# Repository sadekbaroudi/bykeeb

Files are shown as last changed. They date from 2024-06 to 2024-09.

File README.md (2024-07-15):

# bykeeb (baby yoda keyboard)

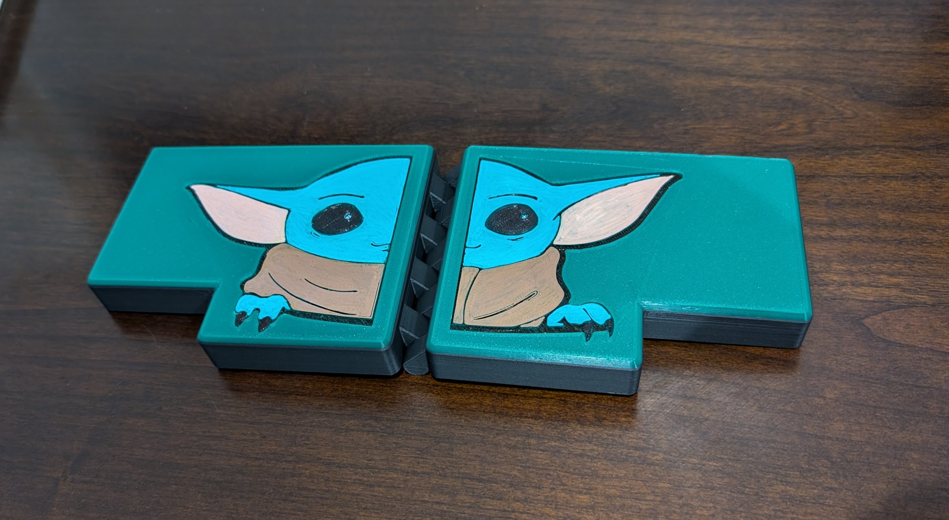
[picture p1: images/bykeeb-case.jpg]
bykeeb-case

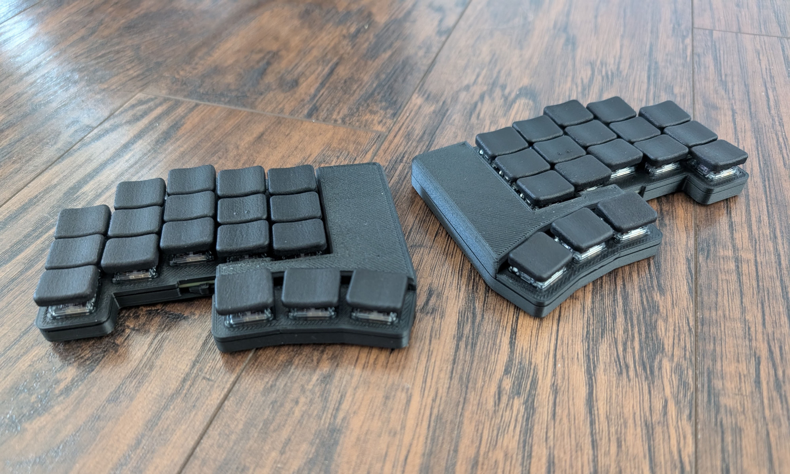
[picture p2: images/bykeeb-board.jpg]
bykeeb-board

bykeeb-in-case

## overview
bykeeb stands for "Baby Yoda Keyboard"

This is a 36 key wireless keyboard using a seeed xiao nrf52840 controller, supporting choc, gateron low profile, and MX switches.

### key features
* 36 keys
* seeed xiao nrf52840 controller
* hotswap or direct solder support for choc, gateron low profile, and MX switches
* battery cutout in pcb for a 32mm x 20mm x 6mm battery
* battery through holes for soldering a JST connector or direct wire
* on/off switch
* reset switch

### important notes
* This keyboard is wireless only. You cannot use a xiao rp2040.
* The switch spacing on this board is what I call min-y standard-x spacing. This is 19mm x 16mm. In the pictures above, I'm using [CMY keycaps](https://github.com/sadekbaroudi/fingerpunch/tree/master/keycaps/CMY).

## firmware

Firmware is done in [ZMK](https://zmk.dev/), and can be found in the [zmk-fingerpunch-keyboards](https://github.com/sadekbaroudi/zmk-fingerpunch-keyboards) github repository, specifically in the `boards/shields/bykeeb` directory.

## build guide

see the [build guide](buildguide/README.md) for more info

## case

see the [case readme](cases/README.md) for more info

## fabrication

Use the `gerber.zip` found in the [pcb directory](pcb/mx-choc-ks-27/production). If you are using [jlcpcb](jlcpcb.com), you can also use the `bom.csv` and `positions.csv` to do PCBA

## LICENSE

Free to use for personal use only. Any derivitive work must reference the author by name, link to [https://github.com/sadekbaroudi/bykeeb](https://github.com/sadekbaroudi/bykeeb), and propagate this license text. No commercial use of this work or any of its derivatives.

THE CONTENT OF THIS REPOSITORY IS PROVIDED "AS IS", WITHOUT WARRANTY OF ANY KIND, EXPRESS OR IMPLIED, INCLUDING BUT NOT LIMITED TO THE WARRANTIES OF MERCHANTABILITY, FITNESS FOR A PARTICULAR PURPOSE AND NONINFRINGEMENT. IN NO EVENT SHALL THE AUTHORS OR COPYRIGHT HOLDERS BE LIABLE FOR ANY CLAIM, DAMAGES OR OTHER LIABILITY, WHETHER IN AN ACTION OF CONTRACT, TORT OR OTHERWISE, ARISING FROM, OUT OF OR IN CONNECTION WITH THE SOFTWARE/HARDWARE OR THE USE OR OTHER DEALINGS IN THE SOFTWARE/HARDWARE.

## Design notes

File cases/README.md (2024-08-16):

# bykeeb case

## parts

For this build, you'll need:
| Required or Optional | Quantity | Part | Notes | 
| --- | --- | --- | --- |
| Required | 1 | left body | |
| Required | 1 | right body | |
| Optional | 1 | left cover | |
| Optional | 1 | right cover | |
| See notes | 1 | left switch plates | Only optional for for choc / glp, required for MX |
| See notes | 1 | right switch plates | Only optional for for choc / glp, required for MX |
| See notes | 6 | M2 heat set inserts, 3.5mm diameter, 3.5-4mm length | Only required if you are using the left and right covers |
| See notes | 6 | M2 screws, 5mm | Only required if you are using the left and right covers |
| Optional | 1 | left on/off switch cover | |
| Optional | 1 | right on/off switch cover | |

### explanation of file names

* `bykeeb-on-off-switch-long` vs `bykeeb-on-off-switch-short` - the long will not fit in the carrying case, but is more convenient to switch on and off. The short one will fit in the carrying case
* `bykeeb-body-left-inset-0.2mm` - The `inset-0.2mm` models go in 0.2mm in the inside perimeter of the body. It's a bit of a tighter fit for the pcb. This is in case the pcb doesn't snap fit into the body well enough for the non-inset version.

## renders
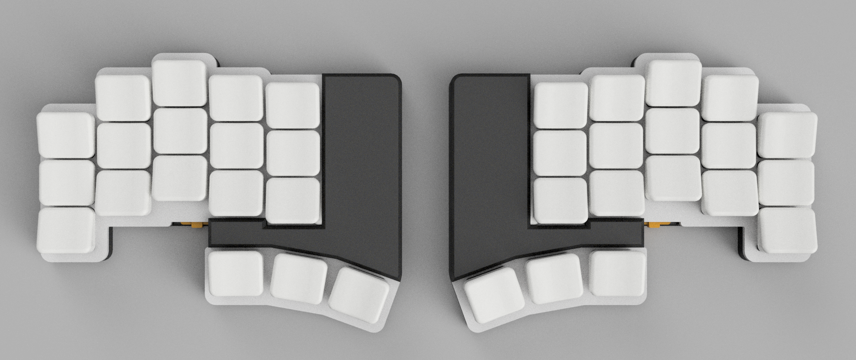
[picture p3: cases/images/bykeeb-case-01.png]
bykeeb-case-01

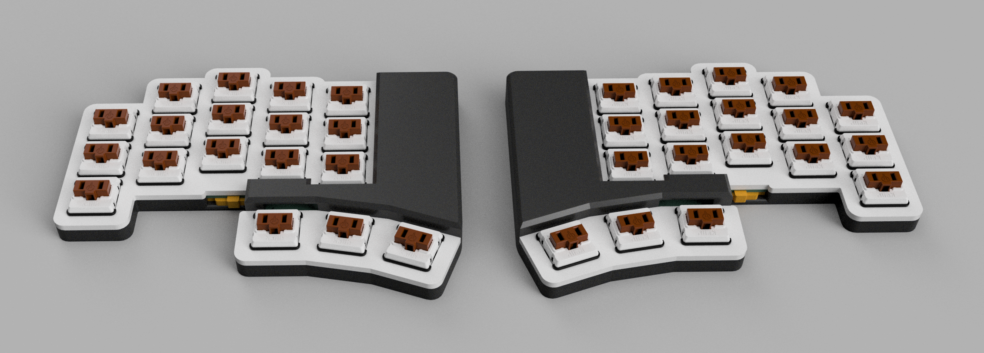
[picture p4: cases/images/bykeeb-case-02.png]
bykeeb-case-01

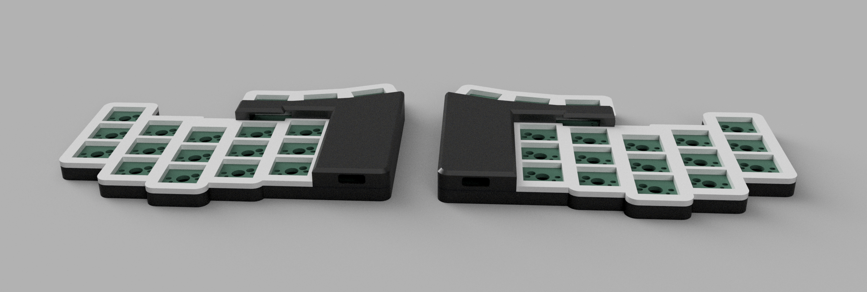
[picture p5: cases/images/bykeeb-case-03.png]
bykeeb-case-01

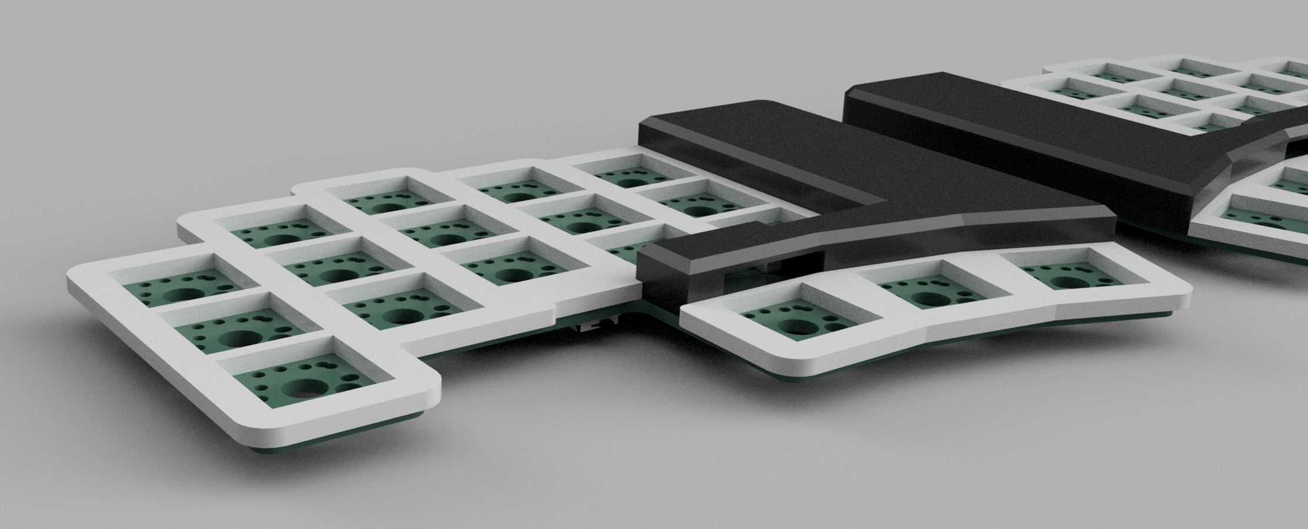
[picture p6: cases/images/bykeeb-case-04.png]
bykeeb-case-01

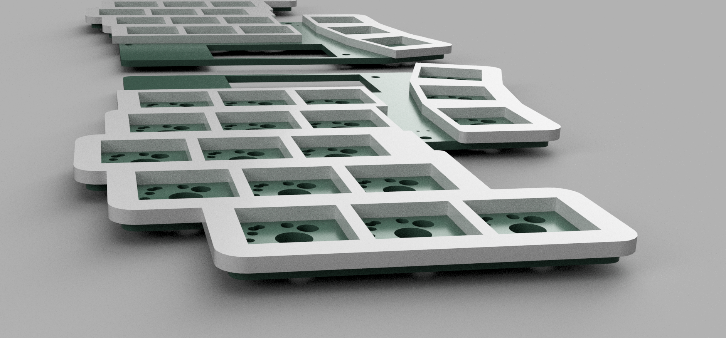
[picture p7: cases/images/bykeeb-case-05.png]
bykeeb-case-01

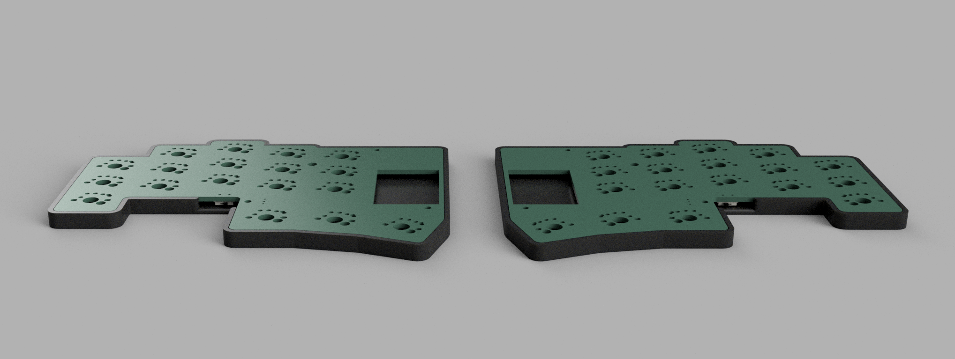
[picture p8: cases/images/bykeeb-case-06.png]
bykeeb-case-01

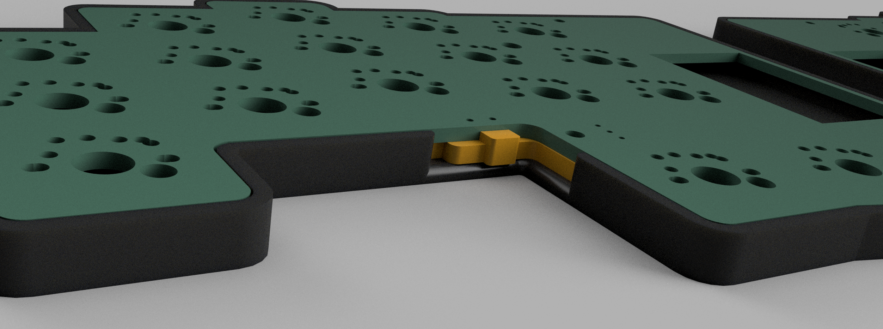
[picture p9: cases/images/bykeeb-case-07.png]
bykeeb-case-01


## assembly

The pcb is a press fit into the body.

For the cover, you should melt the heat set inserts into the mounting points, and then screw into the heat set inserts from the bottom of the pcb.

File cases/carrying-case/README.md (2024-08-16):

# bykeeb carrying case

There are effectively two versions of this case. The print-in-place and the hinge-assembly-required versions. The difference between these two is that the print in place requires that you print the whole case in one print. Recognizing that some print beds are not large enough to accommodate this, I also included the hinge-assembly-required version. In this version, the center hinge for the case is hollowed out to allow you to independently print the left and right halves.

## Print in place

### parts

For this build, you'll need:
| Quantity | Part | Notes |
| --- | --- | --- |
| 6 | 8mm x 3mm magnets | |
| 1 | Rod with diameter: 4.5mm - 5mm and length: ~95mm | |

## Hinge assembly required

## parts

For this build, you'll need:
| Quantity | Part | Notes | 
| --- | --- | --- |
| 6 | 8mm x 3mm magnets | |
| 1 | Rod with diameter: 4.5mm - 5mm and length: ~95mm | The rod should have a mechanism to screw in or cap at either end to allow you to use it as a hinge for the two halves. I don't have any recommendations on where to get this, as I haven't built one myself. |
| 1 | (alternate to rod above) hinge-center-piece stl | If you can print this, it should fit in the center. Not sure how reliable it will be, but worth trying! |

## Magnet assembly

For the magnets on each of these cases, you should put a touch of super glue in the holes for the magnets, and press them in. Be very careful to make sure the magnet's polarity is correct between the two halves!

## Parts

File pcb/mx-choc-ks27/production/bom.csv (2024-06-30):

Designator | Footprint | Quantity | Value | LCSC Part #
 |  | 1
D1, D10, D11, D12, D13, D14, D15, D16, D17, D18, D19, D2, D20, D21, D22, D23, D24, D25, D26, D27, D28, D29, D3, D30, D31, D32, D33, D34, D35, D36, D4, D5, D6, D7, D8, D9 | D_SOD-123 | 36 | 1N4148W | C909967
H1, H2, H3, H4, H5, H6 | MountingHole_2.2mm_M2_DIN965_Pad | 6 | MountingHole
H10, H7, H8, H9 | Breakaway_Tabs | 4 | Breakaway Tabs
H11, H12 | MountingHole_3.2mm_M3 | 2 | MountingHole
J1, J2 | JST_PH_S3B-PH-K_1x03_P2.00mm_Horizontal | 2 | Conn_01x03_Female | C157929
M1, M2 | xiao-ble-smd-cutout | 2 | XIAO-BLE
SW1, SW10, SW11, SW12, SW13, SW14, SW15, SW16, SW17, SW18, SW19, SW2, SW20, SW21, SW22, SW23, SW24, SW25, SW26, SW27, SW28, SW29, SW3, SW30, SW31, SW32, SW33, SW34, SW35, SW36, SW4, SW5, SW6, SW7, SW8, SW9 | gateron-ks27-choc-v1-mx-soldered-and-hotswap | 36 | SW_Push
SW37, SW38 | MSK-12C02 | 2 | SW_DPDT | C431540
U1, U2 | SKQG-1155865 | 2 | SW_Push

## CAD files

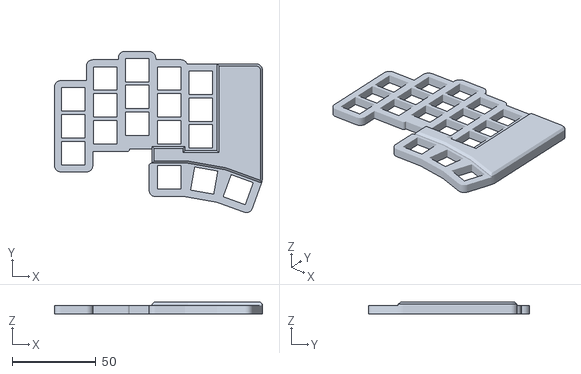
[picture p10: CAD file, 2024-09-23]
cases/bykeeb-cover-integrated-switchplate-mx-left.stl
124.0 x 96.1 x 7.00

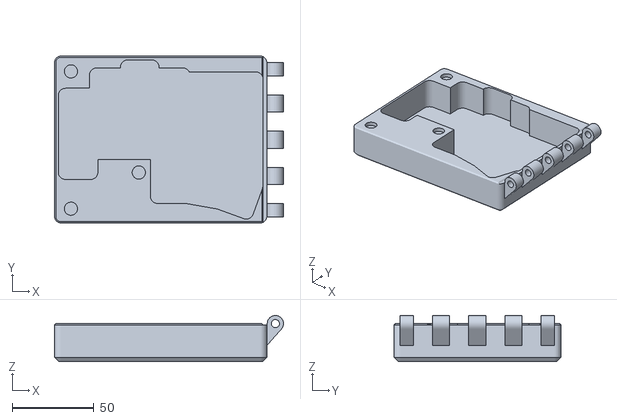
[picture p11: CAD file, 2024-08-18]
cases/carrying-case/hinge-assembly-required/bykeeb-carrying-case-16.7mm-inner-depth-left.stl
140.2 x 102.2 x 28.2

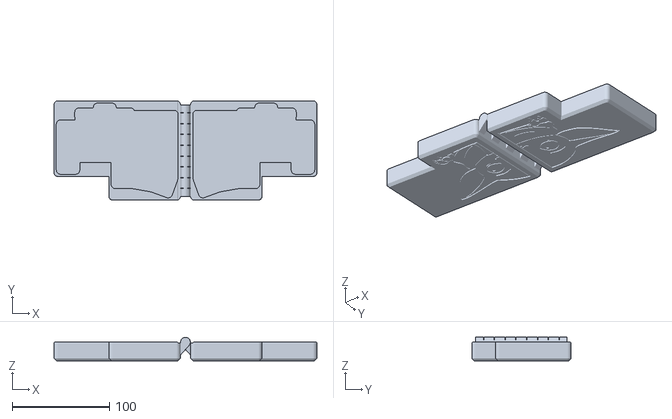
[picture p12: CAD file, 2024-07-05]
cases/carrying-case/print-in-place/bykeeb-carrying-case-16.7mm-inner-depth-non-boxed-grogu-emboss.stl
270.4 x 102.2 x 24.2

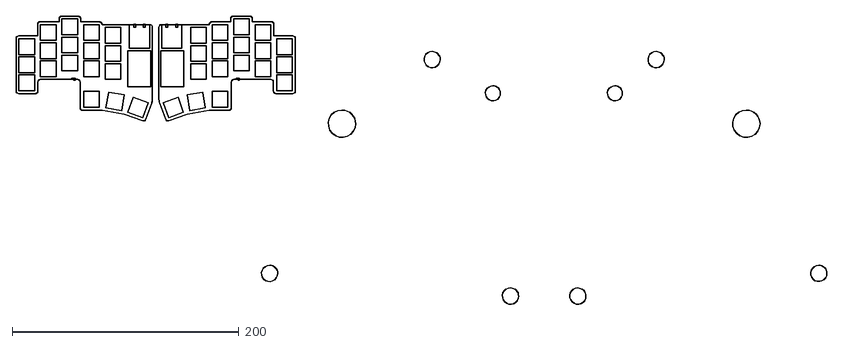
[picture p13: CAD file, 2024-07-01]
svgs/bykeeb-case-sketch.dxf
715.8 x 254.9

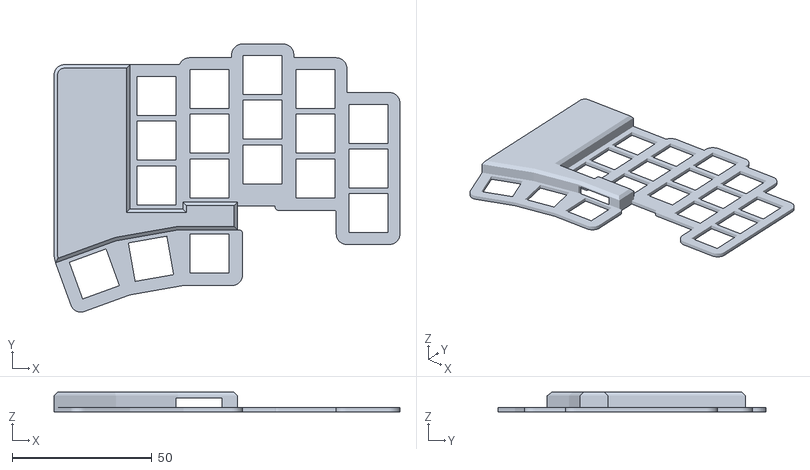
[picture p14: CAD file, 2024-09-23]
cases/bykeeb-cover-integrated-switchplate-choc-right.stl
124.0 x 96.1 x 7.00

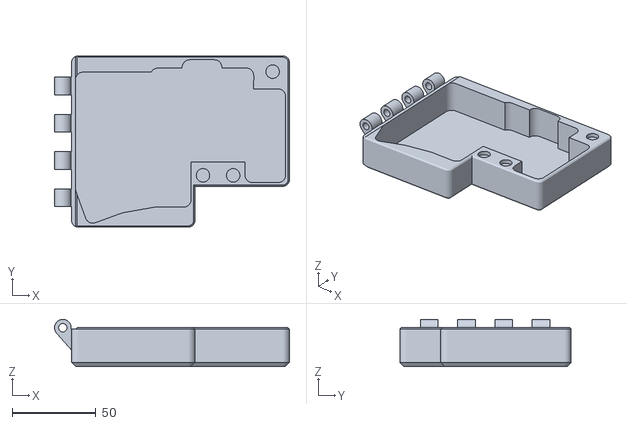
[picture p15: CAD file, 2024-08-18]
cases/carrying-case/hinge-assembly-required/bykeeb-carrying-case-non-boxed-20.7mm-inner-depth-right.stl
140.2 x 102.2 x 28.2

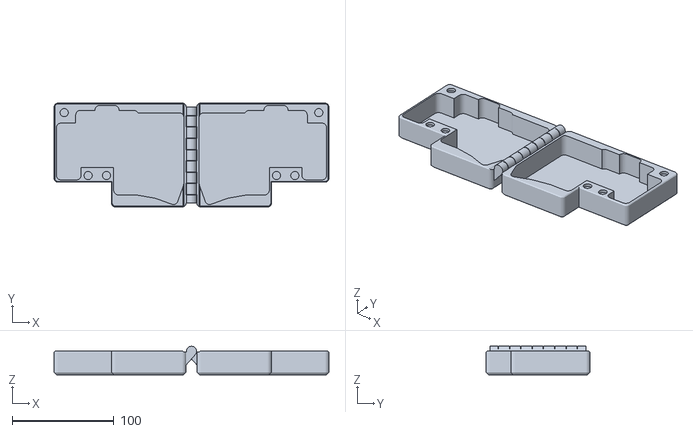
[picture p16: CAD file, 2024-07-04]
cases/carrying-case/print-in-place/bykeeb-carrying-case-20.7mm-inner-depth-non-boxed.stl
270.4 x 102.2 x 28.2

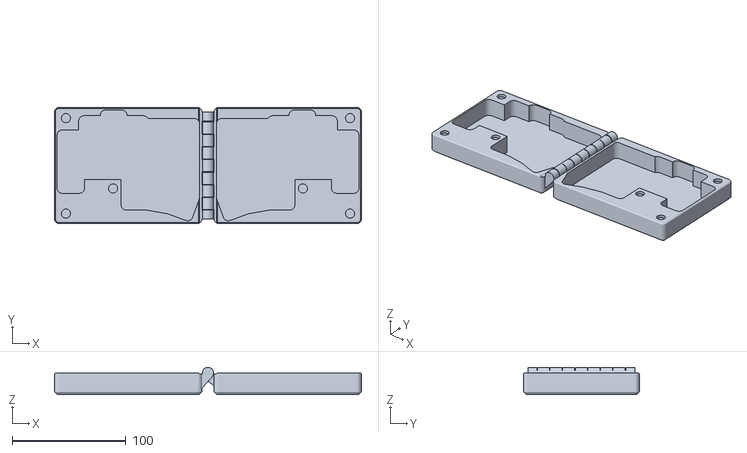
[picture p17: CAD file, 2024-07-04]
cases/carrying-case/print-in-place/bykeeb-carrying-case-16.7mm-inner-depth.stl
270.4 x 102.2 x 24.2

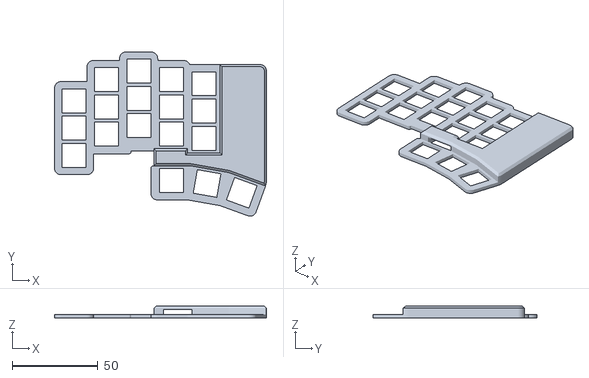
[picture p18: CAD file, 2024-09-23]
cases/bykeeb-cover-integrated-switchplate-glp-left.stl
124.0 x 96.1 x 7.00

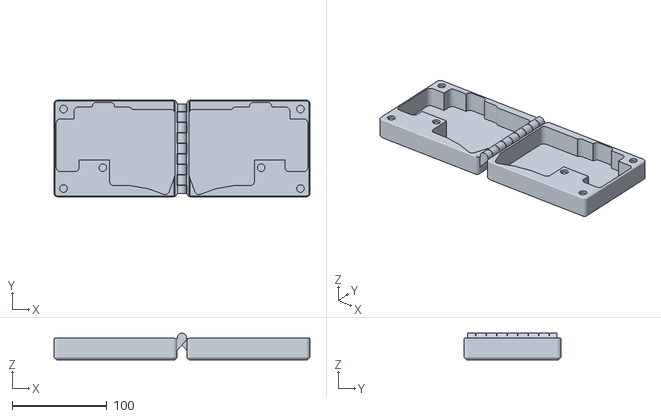
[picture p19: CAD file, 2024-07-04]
cases/carrying-case/print-in-place/bykeeb-carrying-case-20.7mm-inner-depth.stl
270.4 x 102.2 x 28.2

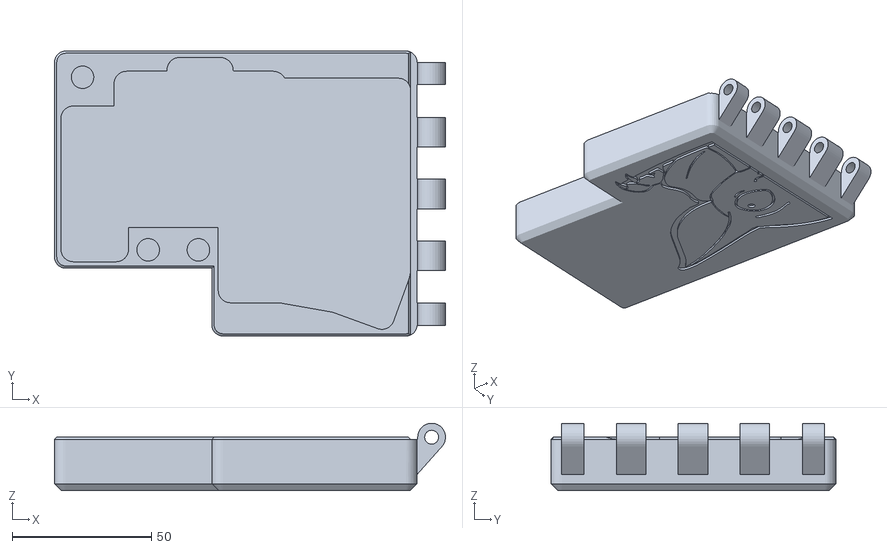
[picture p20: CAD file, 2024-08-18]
cases/carrying-case/hinge-assembly-required/bykeeb-carrying-case-non-boxed-16.7mm-inner-depth-grogu-emboss-left.stl
140.2 x 102.2 x 24.2

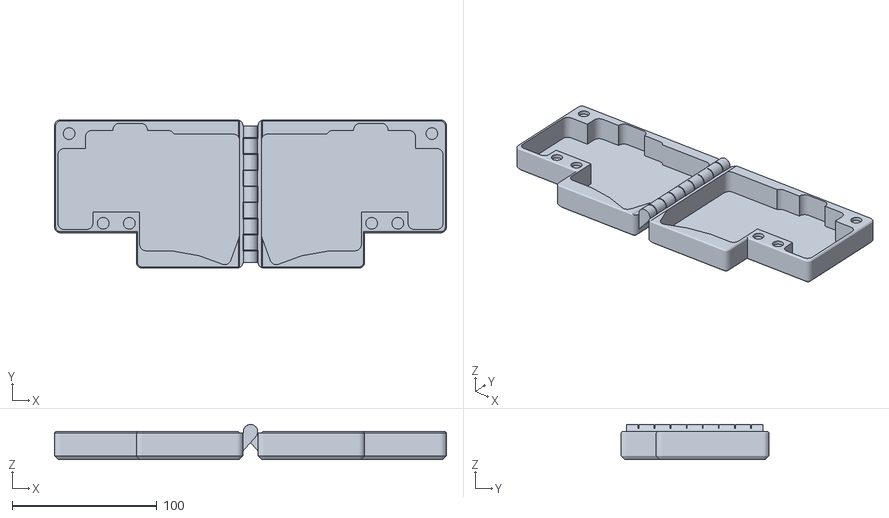
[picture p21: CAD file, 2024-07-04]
cases/carrying-case/print-in-place/bykeeb-carrying-case-16.7mm-inner-depth-non-boxed.stl
270.4 x 102.2 x 24.2

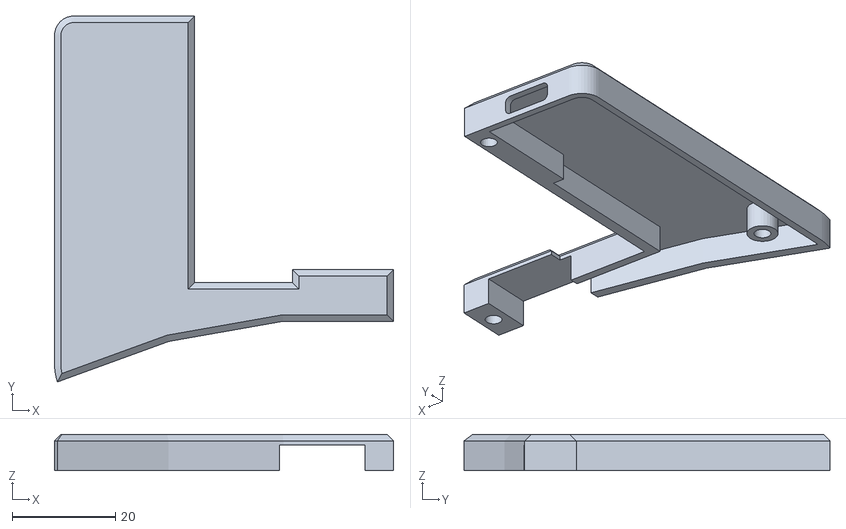
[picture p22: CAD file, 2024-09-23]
cases/bykeeb-cover-right.stl
65.8 x 71.0 x 7.00

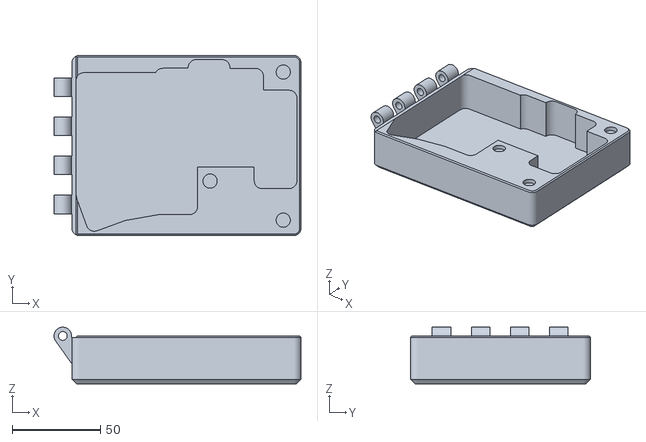
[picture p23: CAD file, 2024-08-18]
cases/carrying-case/hinge-assembly-required/bykeeb-carrying-case-20.7mm-inner-depth-right.stl
140.2 x 102.2 x 32.2

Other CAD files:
cases/bykeeb-cover-integrated-switchplate-mx-right.stl
cases/carrying-case/hinge-assembly-required/bykeeb-carrying-case-16.7mm-inner-depth-right.stl
cases/carrying-case/hinge-assembly-required/bykeeb-carrying-case-non-boxed-20.7mm-inner-depth-left.stl
cases/bykeeb-cover-integrated-switchplate-choc-left.stl
cases/bykeeb-body-left-inset-0.2mm.stl
cases/bykeeb-body-left.stl
cases/bykeeb-body-right-inset-0.2mm.stl
cases/bykeeb-body-right.stl
cases/bykeeb-cover-integrated-switchplate-glp-right.stl
cases/bykeeb-cover-left.stl
cases/bykeeb-on-off-switch-long-left.stl
cases/bykeeb-on-off-switch-long-right.stl
cases/bykeeb-on-off-switch-short-left.stl
cases/bykeeb-on-off-switch-short-right.stl
cases/bykeeb-switchplate-choc-or-glp-alphas.stl
cases/bykeeb-switchplate-choc-or-glp-thumbs.stl
cases/bykeeb-switchplate-mx-alphas.stl
cases/bykeeb-switchplate-mx-thumbs.stl
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

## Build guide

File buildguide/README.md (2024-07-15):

# build guide

## steps

(Note that there are additional images at the bottom of this guide as references for the build process)

1. Solder all the diodes. The line marking on the diode should be on the side closer to the diode silkscreen with a vertical line closing off the two horizontal lines
2. Solder the reset switch. The orientation doesn't matter
3. Solder the on/off switch. There is only one orientation for this. After soldering, **make sure the switch is in the off position**.
4. If using hotswap, solder all the hotswap sockets
5. Pre-solder the pads on the xiao controller, as shown below. For the battery pads, try to get only half the pad. If you get the right half covered in solder, the xiao pcb won't sit flush on the bykeeb pcb.
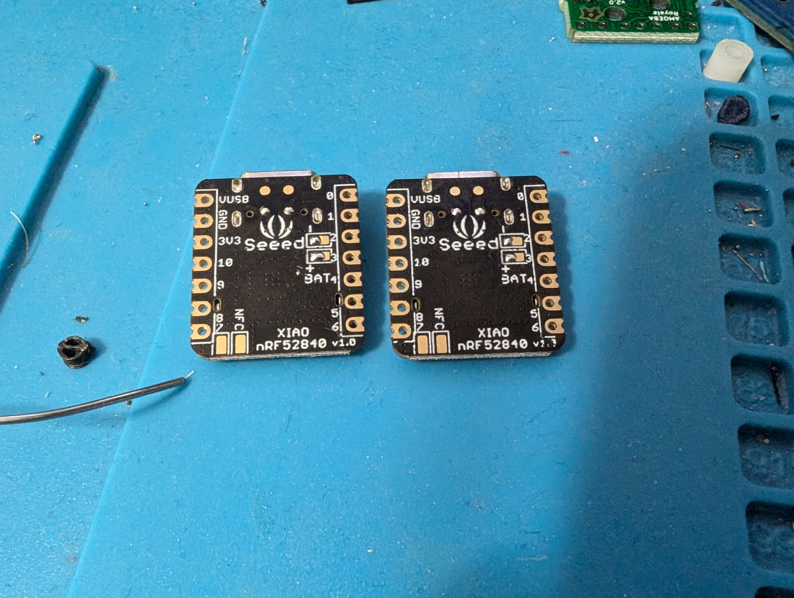
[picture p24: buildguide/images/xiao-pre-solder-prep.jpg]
bykeeb-image

6. After soldering all the castellated pads of the xiao to the top side of the bykeeb, flip the board over and solder the through holes. The reason that wetting the pads in step 5 was important is that now you can pull the solder up with the soldering iron to make a good connection. See below.
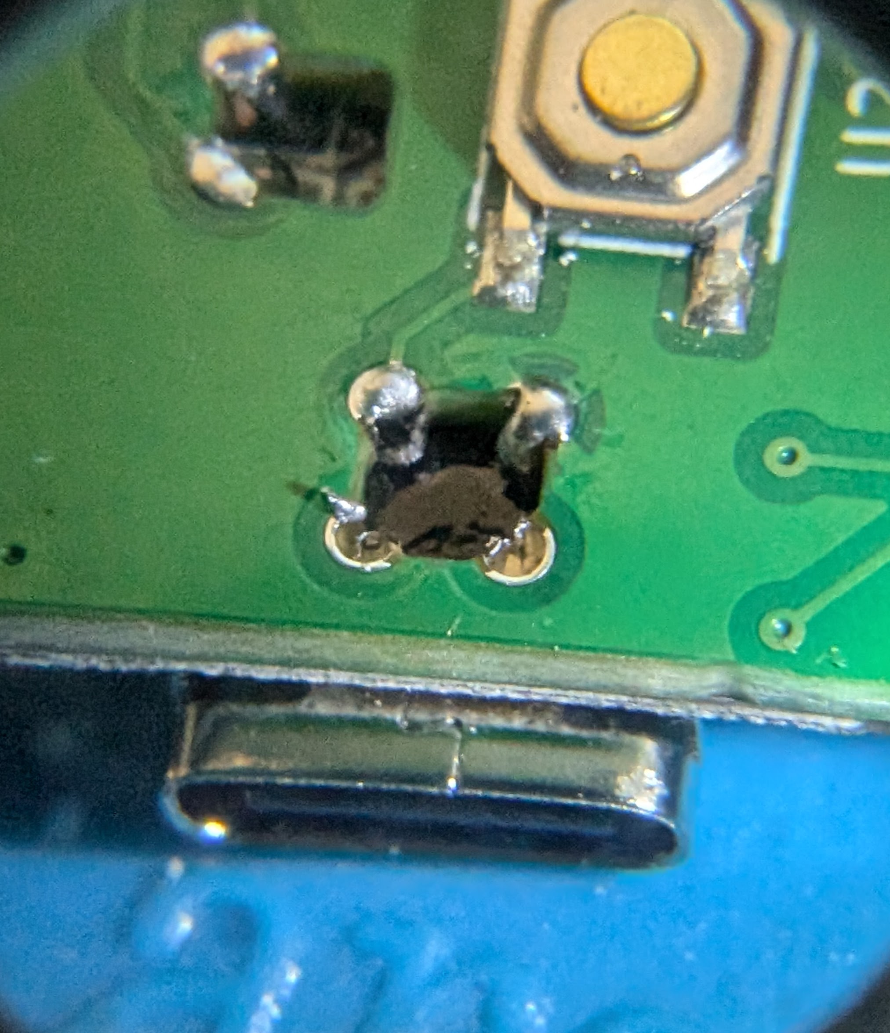
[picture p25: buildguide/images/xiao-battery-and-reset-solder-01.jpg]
bykeeb-image

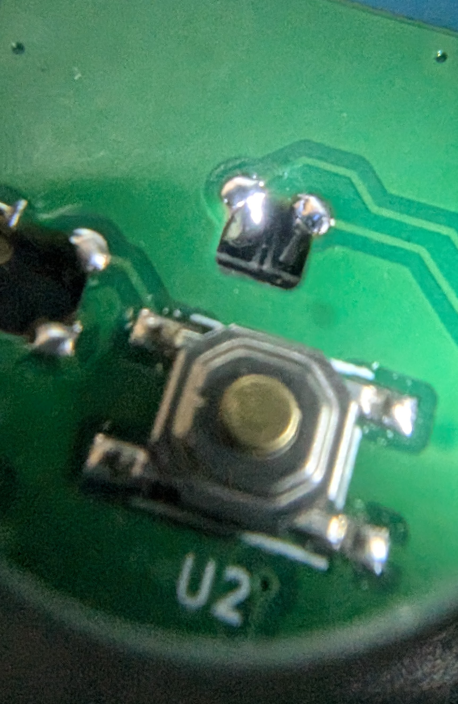
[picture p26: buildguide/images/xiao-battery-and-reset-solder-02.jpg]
bykeeb-image

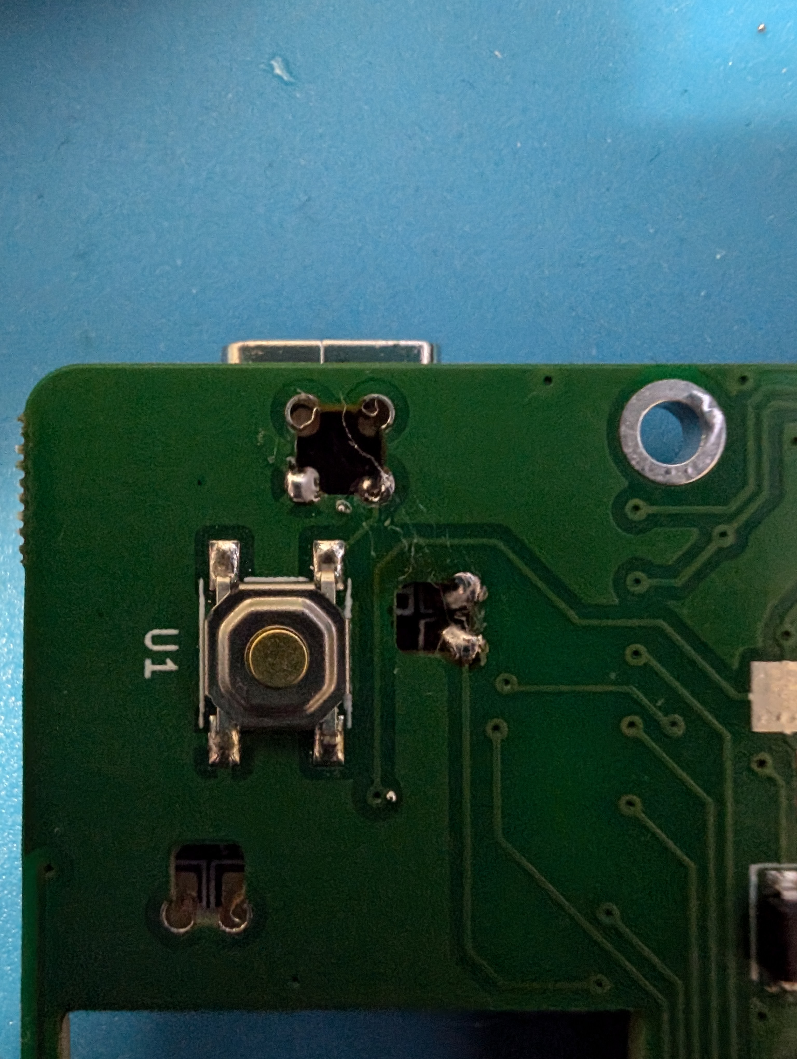
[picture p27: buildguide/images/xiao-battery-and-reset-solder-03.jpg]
bykeeb-image

7. If you're building without hotswap sockets, place the switches into the through holes, and solder them. Please note that if you want to use switch plates, you **must** have them in place before this step, or you won't be able to add them later.
8. Solder the JST connector to the top sides of the bykeeb halves. It is very important that you know the polarity of your battery before soldering this. You can plug in the battery into the JST connector before soldering. The through holes on the outside are the B- (ground) connections, and the single center through hole is the B+ (VCC). So, the red wire of the battery should go to the center through hole (B+).

You're done assembling the PCB!

## images

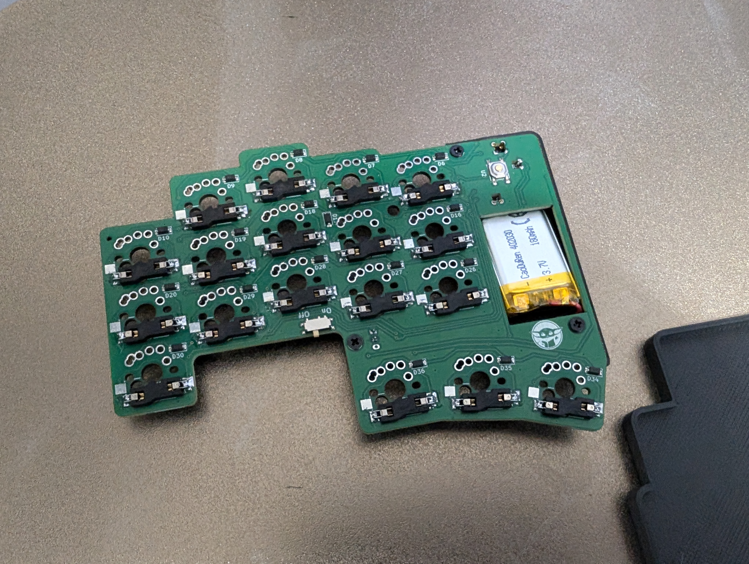
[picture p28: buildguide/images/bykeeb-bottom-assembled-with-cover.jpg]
bykeeb-image

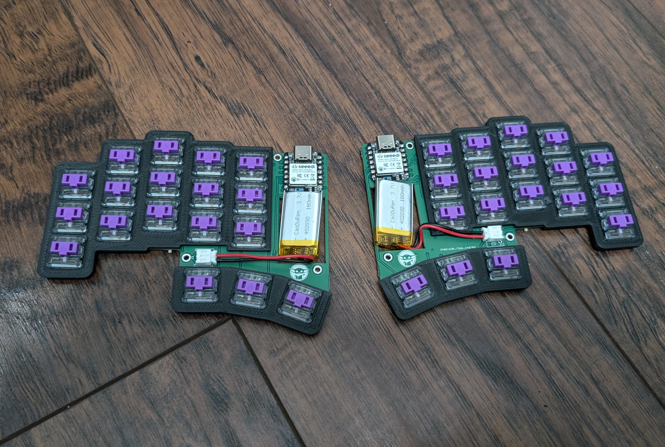
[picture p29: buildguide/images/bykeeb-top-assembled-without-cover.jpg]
bykeeb-image

bykeeb-image
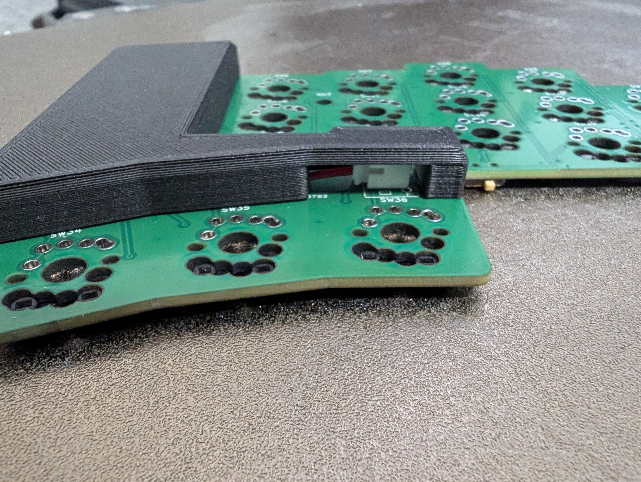
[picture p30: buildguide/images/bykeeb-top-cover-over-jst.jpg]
bykeeb-image

bykeeb-image

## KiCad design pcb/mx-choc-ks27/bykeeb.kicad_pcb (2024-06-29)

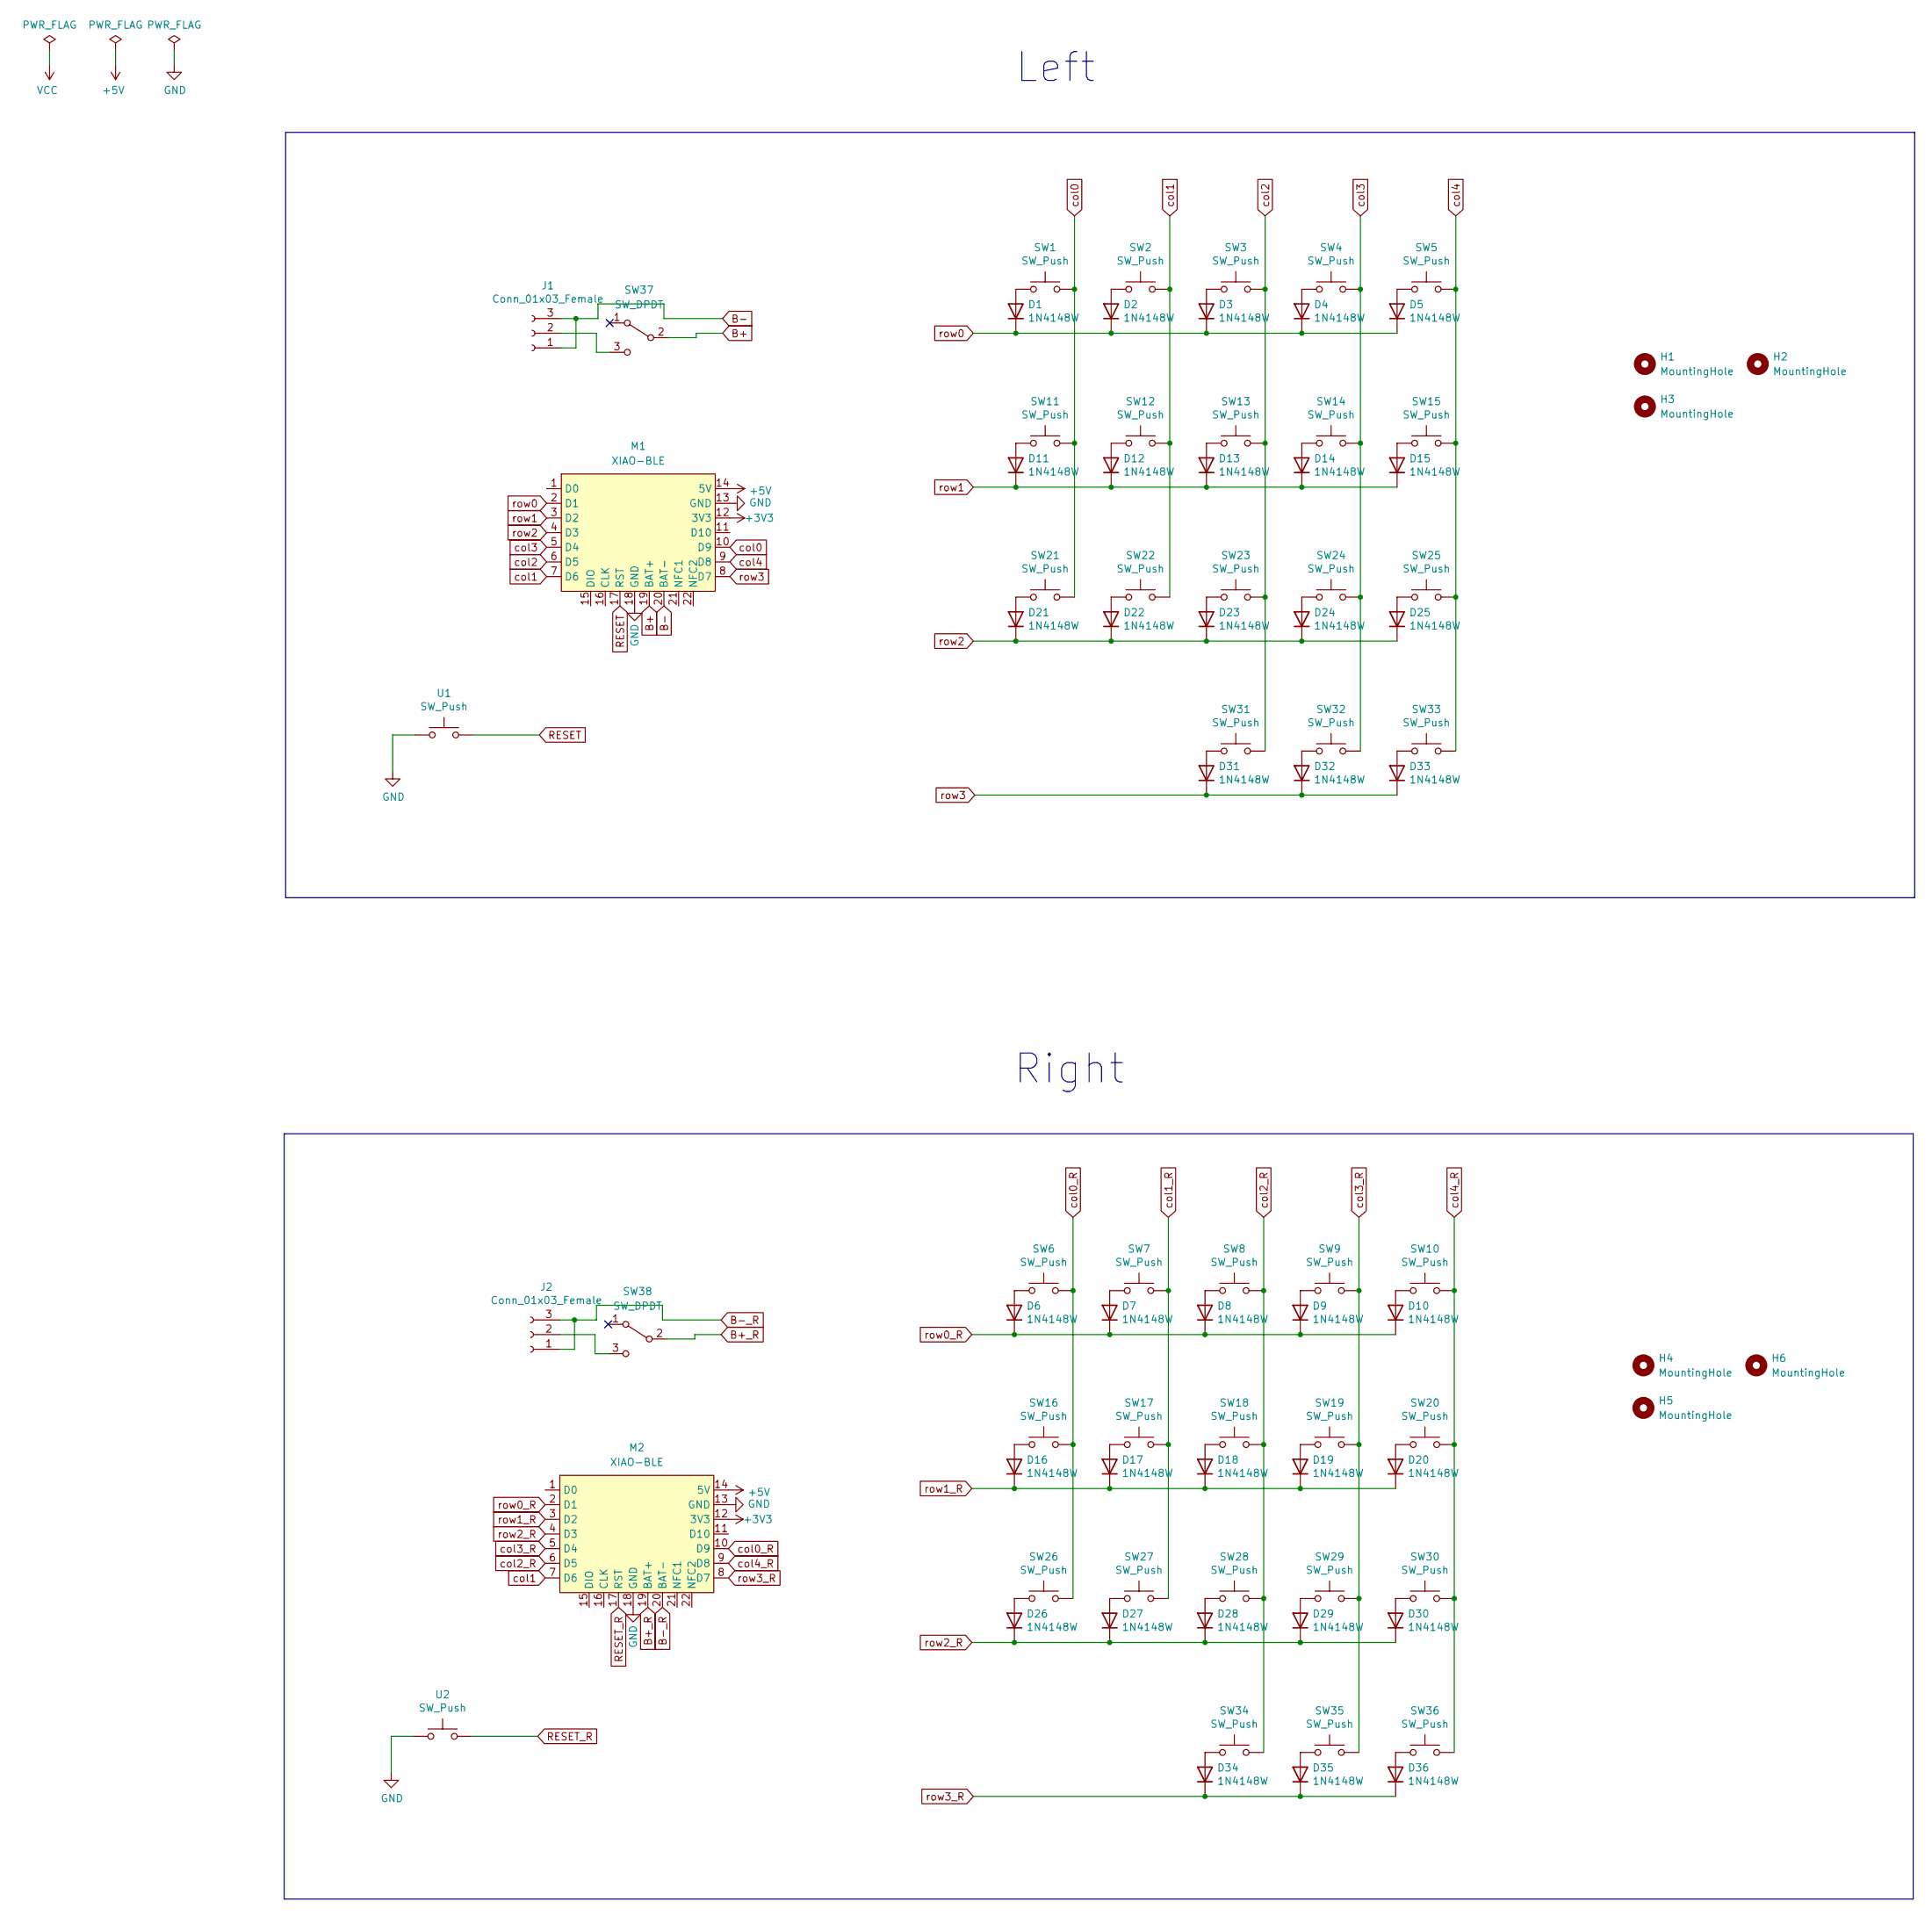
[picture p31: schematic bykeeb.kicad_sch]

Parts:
D1, D2, D3, D4, D5, D6, D7, D8, D9, D10, D11, D12, D13, D14, D15, D16, D17, D18, D19, D20, D21, D22, D23, D24, D25, D26, D27, D28, D29, D30, D31, D32, D33, D34, D35, D36: 1N4148W; D_SOD-123; LCSC C909967
H1, H2, H3, H4, H5, H6: MountingHole; MountingHole_2.2mm_M2_DIN965_Pad
J1, J2: Conn_01x03_Female; JST_PH_S3B-PH-K_1x03_P2.00mm_Horizontal; LCSC C157929
M1, M2: XIAO-BLE; xiao-ble-smd-cutout
SW1, SW2, SW3, SW4, SW5, SW6, SW7, SW8, SW9, SW10, SW11, SW12, SW13, SW14, SW15, SW16, SW17, SW18, SW19, SW20, SW21, SW22, SW23, SW24, SW25, SW26, SW27, SW28, SW29, SW30, SW31, SW32, SW33, SW34, SW35, SW36: SW_Push; gateron-ks27-choc-v1-mx-soldered-and-hotswap
SW37, SW38: SW_DPDT; MSK-12C02; LCSC C431540
U1, U2: SW_Push; SKQG-1155865

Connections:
+3V3: M1.12 (3V3), M2.12 (3V3)
+5V: M1.14 (5V), M2.14 (5V)
B+: M1.19 (BAT+), SW37.2 (B)
B+_R: M2.19 (BAT+), SW38.2 (B)
B-: J1.1, J1.3, M1.20 (BAT-)
B-_R: J2.1, J2.3, M2.20 (BAT-)
GND: M1.13 (GND), M1.18 (GND), M2.13 (GND), M2.18 (GND), U1.1, U2.1
unnamed: D1.2 (A), SW1.1
unnamed: D2.2 (A), SW2.1
unnamed: D3.2 (A), SW3.1
unnamed: D4.2 (A), SW4.1
unnamed: D5.2 (A), SW5.1
unnamed: D6.2 (A), SW6.1
unnamed: D7.2 (A), SW7.1
unnamed: D8.2 (A), SW8.1
unnamed: D9.2 (A), SW9.1
unnamed: D10.2 (A), SW10.1
unnamed: D11.2 (A), SW11.1
unnamed: D12.2 (A), SW12.1
unnamed: D13.2 (A), SW13.1
unnamed: D14.2 (A), SW14.1
unnamed: D15.2 (A), SW15.1
unnamed: D16.2 (A), SW16.1
unnamed: D17.2 (A), SW17.1
unnamed: D18.2 (A), SW18.1
unnamed: D19.2 (A), SW19.1
unnamed: D20.2 (A), SW20.1
unnamed: D21.2 (A), SW21.1
unnamed: D22.2 (A), SW22.1
unnamed: D23.2 (A), SW23.1
unnamed: D24.2 (A), SW24.1
unnamed: D25.2 (A), SW25.1
unnamed: D26.2 (A), SW26.1
unnamed: D27.2 (A), SW27.1
unnamed: D28.2 (A), SW28.1
unnamed: D29.2 (A), SW29.1
unnamed: D30.2 (A), SW30.1
unnamed: D31.2 (A), SW31.1
unnamed: D32.2 (A), SW32.1
unnamed: D33.2 (A), SW33.1
unnamed: D34.2 (A), SW34.1
unnamed: D35.2 (A), SW35.1
unnamed: D36.2 (A), SW36.1
unnamed: J1.2, SW37.3 (C)
unnamed: J2.2, SW38.3 (C)
RESET: M1.17 (RST), U1.2
RESET_R: M2.17 (RST), U2.2
col0: M1.10 (D9), SW1.2, SW11.2, SW21.2
col0_R: M2.10 (D9), SW6.2, SW16.2, SW26.2
col1: M1.7 (D6), M2.7 (D6), SW2.2, SW12.2, SW22.2
col1_R: SW7.2, SW17.2, SW27.2
col2: M1.6 (D5), SW3.2, SW13.2, SW23.2, SW31.2
col2_R: M2.6 (D5), SW8.2, SW18.2, SW28.2, SW34.2
col3: M1.5 (D4), SW4.2, SW14.2, SW24.2, SW32.2
col3_R: M2.5 (D4), SW9.2, SW19.2, SW29.2, SW35.2
col4: M1.9 (D8), SW5.2, SW15.2, SW25.2, SW33.2
col4_R: M2.9 (D8), SW10.2, SW20.2, SW30.2, SW36.2
row0: D1.1 (K), D2.1 (K), D3.1 (K), D4.1 (K), D5.1 (K), M1.2 (D1)
row0_R: D6.1 (K), D7.1 (K), D8.1 (K), D9.1 (K), D10.1 (K), M2.2 (D1)
row1: D11.1 (K), D12.1 (K), D13.1 (K), D14.1 (K), D15.1 (K), M1.3 (D2)
row1_R: D16.1 (K), D17.1 (K), D18.1 (K), D19.1 (K), D20.1 (K), M2.3 (D2)
row2: D21.1 (K), D22.1 (K), D23.1 (K), D24.1 (K), D25.1 (K), M1.4 (D3)
row2_R: D26.1 (K), D27.1 (K), D28.1 (K), D29.1 (K), D30.1 (K), M2.4 (D3)
row3: D31.1 (K), D32.1 (K), D33.1 (K), M1.8 (D7)
row3_R: D34.1 (K), D35.1 (K), D36.1 (K), M2.8 (D7)

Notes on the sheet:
Left
Right

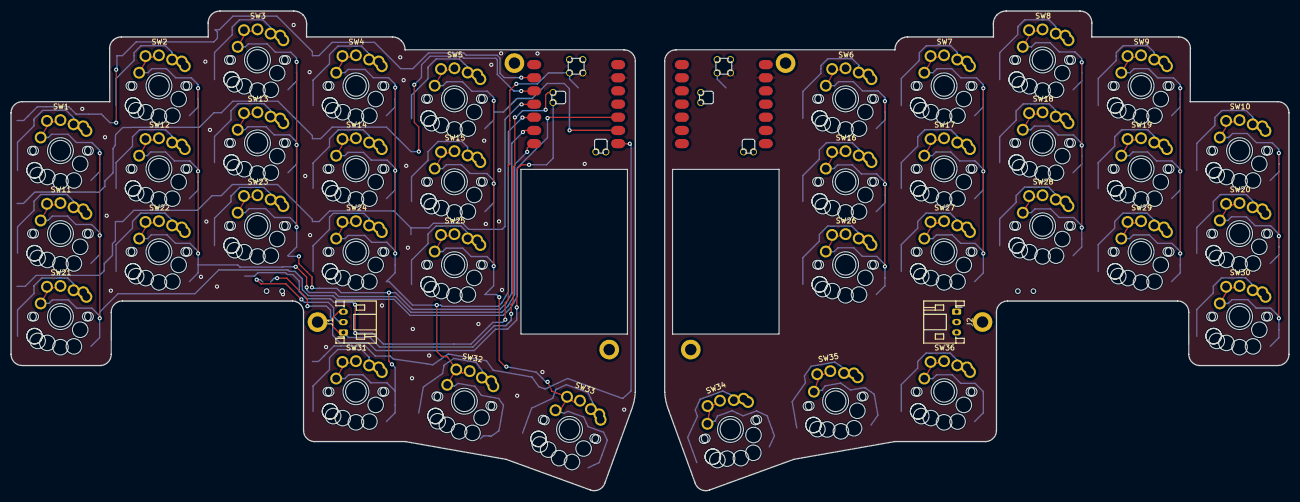
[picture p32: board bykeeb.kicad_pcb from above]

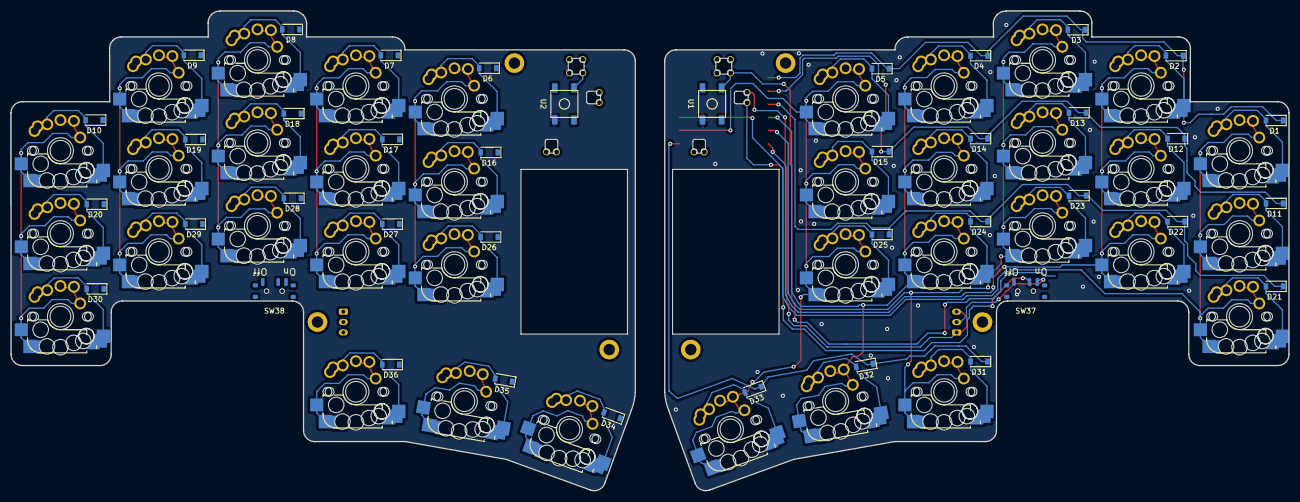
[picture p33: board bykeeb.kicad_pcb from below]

Board: 2 copper layers, 246.5 x 92.5 mm, 86 parts (40 on the bottom side), 65 nets.

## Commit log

2024-06-29 initial commit, almost done routing
    [bom.csv, bykeeb.kicad_pcb, bykeeb.kicad_sch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]
2024-06-30 ready for prototype run
    [bom.csv, bykeeb.kicad_sch, designators.csv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]
2024-06-30 mounting holes on each side in case we want to try out vik trackpoint support
    [bom.csv, bykeeb.kicad_sch, designators.csv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]
2024-07-01 bykeeb case, reduced wall width, added lip to hold pcb at right height, bumpon recesses in bottom
    [bykeeb-body.stl]
2024-07-01 bykeeb svgs to help make a case
    [bykeeb-case-sketch.dxf]
2024-07-01 case files with basic readme, and bykeeb step file
    [bykeeb-body.stl, bykeeb-cover.stl]
2024-07-02 fixed the cover, and added a carrying case with a print in place hinge
    [bykeeb-carrying-case.stl, bykeeb-cover.stl]
2024-07-03 added more bykeeb carrying case options
    [bykeeb-carrying-case-16.7mm-inner-depth.stl, bykeeb-carrying-case-20.7mm-inner-depth-2x-hinge-joints.stl, bykeeb-carrying-case-20.7mm-inner-depth.stl]
2024-07-03 reduced footprint version of bykeeb carrying case
    [bykeeb-carrying-case-16.7mm-inner-depth-non-boxed.stl, bykeeb-carrying-case-20.7mm-inner-depth-non-boxed.stl]
2024-07-03 bykeeb carrying case with handles
    [bykeeb-carrying-case-20.7mm-inner-depth-with-handle.stl]
2024-07-04 added versions with hinge clearance, in case the sides near the hinge are colliding
    [bykeeb-carrying-case-16.7mm-inner-depth-hinge-clearance.stl, bykeeb-carrying-case-16.7mm-inner-depth-non-boxed-hinge-clearance.stl, bykeeb-carrying-case-16.7mm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]
2024-07-04 added chamfer on cases inside, and reduced magnet hole depth to 2.6mm to let it stick out a tiny bit for better connection
    [bykeeb-carrying-case-16.7mm-inner-depth-hinge-clearance.stl, bykeeb-carrying-case-16.7mm-inner-depth-non-boxed-hinge-clearance.stl, bykeeb-carrying-case-20.7mm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]
2024-07-04 cleaned up unwanted carrying case files
    [bykeeb-carrying-case-16.7mm-inner-depth.stl, bykeeb-carrying-case-20.7mm-inner-depth-with-handle.stl, bykeeb-carrying-case-20.7mm-inner-depth.stl]
2024-07-05 grogu emboss version and renamed existing cases to remove hinge-clearance, as all of them have it now
    [bykeeb-carrying-case-16.7mm-inner-depth-non-boxed-grogu-emboss.stl, bykeeb-carrying-case-16.7mm-inner-depth-non-boxed.stl, bykeeb-carrying-case-16.7mm-inner-de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]
2024-07-05 svg for embossed carrying case
2024-07-10 added tighter case for better press fit pcb into body
    [bykeeb-body-0.2mm-gap.stl, bykeeb-body.stl]
2024-07-11 switch plates for bykeeb
    [bykeeb-switchplate-choc-alphas-left.stl, bykeeb-switchplate-choc-thumbs-left.stl, bykeeb-switchplate-glp-alphas-left.stl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]
2024-07-12 renamed stls that can be reversible, and added cover right side
    [bykeeb-cover-left.stl, bykeeb-cover-right.stl, bykeeb-switchplate-choc-alphas.stl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]
2024-07-12 updated reset hole on right half of case body
    [bykeeb-body-left.stl, bykeeb-body-right.stl]
2024-07-13 on off switch covers, short for carrying case, long otherwise
    [bykeeb-on-off-switch-long-left.stl, bykeeb-on-off-switch-long-right.stl, bykeeb-on-off-switch-short-left.stl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]
2024-07-13 choc and glp plates are actually the same
    [bykeeb-switchplate-choc-alphas.stl, bykeeb-switchplate-choc-or-glp-alphas.stl, bykeeb-switchplate-choc-or-glp-thumbs.stl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]
2024-07-15 added silkscreens to indicate battery polarity
2024-08-09 bykeeb body with inset 0.2mm for situations that requires for tighter pcb fit
    [bykeeb-body-left-inset-0.2mm.stl, bykeeb-body-right-inset-0.2mm.stl]
2024-08-16 added two piece carrying case, and restructured cases folder a bit
    [bykeeb-body-0.2mm-gap.stl, bykeeb-carrying-case-16.7mm-inner-depth-left.stl, bykeeb-carrying-case-16.7mm-inner-depth-non-boxed-grogu-emboss.stl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]
2024-08-16 center piece for hinge-assembly-required carrying case
    [bykeeb-carrying-case-hinge-center-piece.stl]
2024-08-18 updated existing hinge assembly required versions to include channel for better closing, and added new non-boxed versions
    [bykeeb-carrying-case-16.7mm-inner-depth-left.stl, bykeeb-carrying-case-16.7mm-inner-depth-right.stl, bykeeb-carrying-case-20.7mm-inner-depth-left.stl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]
2024-09-23 fixed usb cutout location and added integrated cover plus switchplate combo stls
    [bykeeb-cover-integrated-switchplate-choc-left.stl, bykeeb-cover-integrated-switchplate-choc-right.stl, bykeeb-cover-integrated-switchplate-glp-left.stl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]
